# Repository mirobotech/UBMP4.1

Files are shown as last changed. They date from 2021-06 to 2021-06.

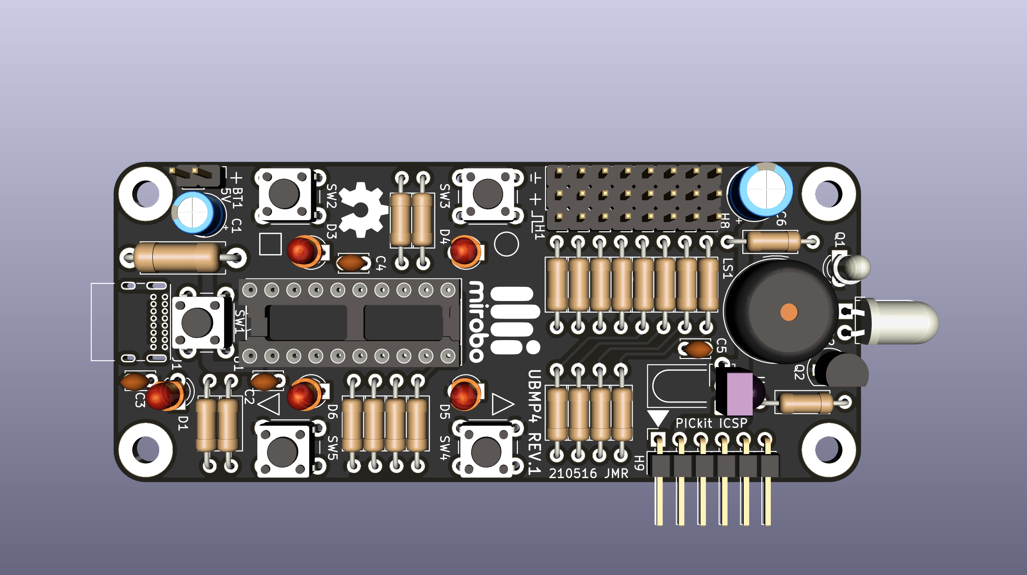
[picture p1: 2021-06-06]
UBMP4.1-top-black.png

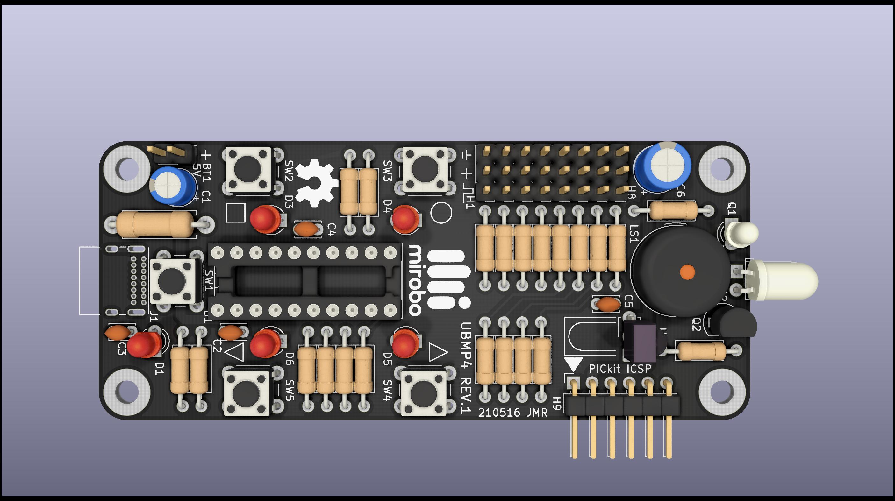
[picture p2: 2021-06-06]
UBMP4.1-top-black.jpg

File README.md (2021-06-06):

# UBMP4.1

UBMP4.1 (USB-Based Beginner Multipurpose Project 4 rev. 1) KiCad schematic and PCB design files.

UBMP4 1-top-black

UBMP4.1 is a development board for learning or teaching PICmicro programming in C using almost any device – including Chromebooks!

## UBMP4.1 Hardware Features

- Microchip PIC16F1459 USB-capable microcontroller with 8k words of program FLASH (6k words free when using the USB bootloader), 128B of user FLASH, 1kB of RAM, 10-bit ADC, and a built-in temperature sensor
- 5 built-in pushbuttons
- 5 visible light LEDs
- 1 piezo beeper output
- optional 8-pin header for PORTC I/O pin expansion (great for servos, a SONAR module, NeoPixels, an LCD, etc.)
- optional IR LED output for remote control transmitter applications (or a high-current transistor-driven output)
- optional IR demodulator for remote control decoding
- optional IR phototransistor or visible-light ambient light sensor for light sensing
- USB 2.0 type-C port for power and programming
- 6-pin ICSP (In-Circuit Serial Programming) header for PICkit-4

## UBMP4.1 Software Features

UBMP4.1 uses the [USB uC](https://github.com/johnnydrazzi/USB-uC) bootloader, which makes UBMP4.1 appear as a USB mass storage device. Programs can be developed in C or assembly code using Microchip Technology's MPLAB X IDE or the MPLAB Xpress web-based IDE, or in any programming language or software that creates a Microchip-compatible .hex output file.

Just plug UBMP4.1 into a USB port, wait for it to appear on your computer as drive ***PIC16F1459***, and drag your compiled .hex file onto the drive. UMBP4.1 starts running your program as soon as the .hex file is transferred.

## UMBP4.1 is Open

UBMP4.1 is open hardware and uses open source software. The following permissions and conditions apply to UBMP4.1:
- the KiCad UBMP4.1 files stored in GitHub are open hardware licensed under the terms of the MIT license (except the mirobo.tech logo - see below)
- UBMP4.1 programs stored in GitHub are open source software licensed under the terms of the MIT license
- UMBP4.1 learning materials on the mirobo.tech website are licensed under the terms of the Creative Commons CC-BY 4.0 license
- the USB uC bootloader is open source and licensed under the terms of the GPL3.0 license by John Izzard
- the mirobo.tech logo mark is a trademark of mirobo Technolgy and may not be used without prior permission

## Where can I buy UBMP4.1?

UBMP4.1 boards and kits are available at [mirobo.tech](https://mirobo.tech/ubmp4).  
Bare UBMP4.1 printed circuit boards are also available from [OSHPARK](https://oshpark.com/shared_projects/b04AabPV).

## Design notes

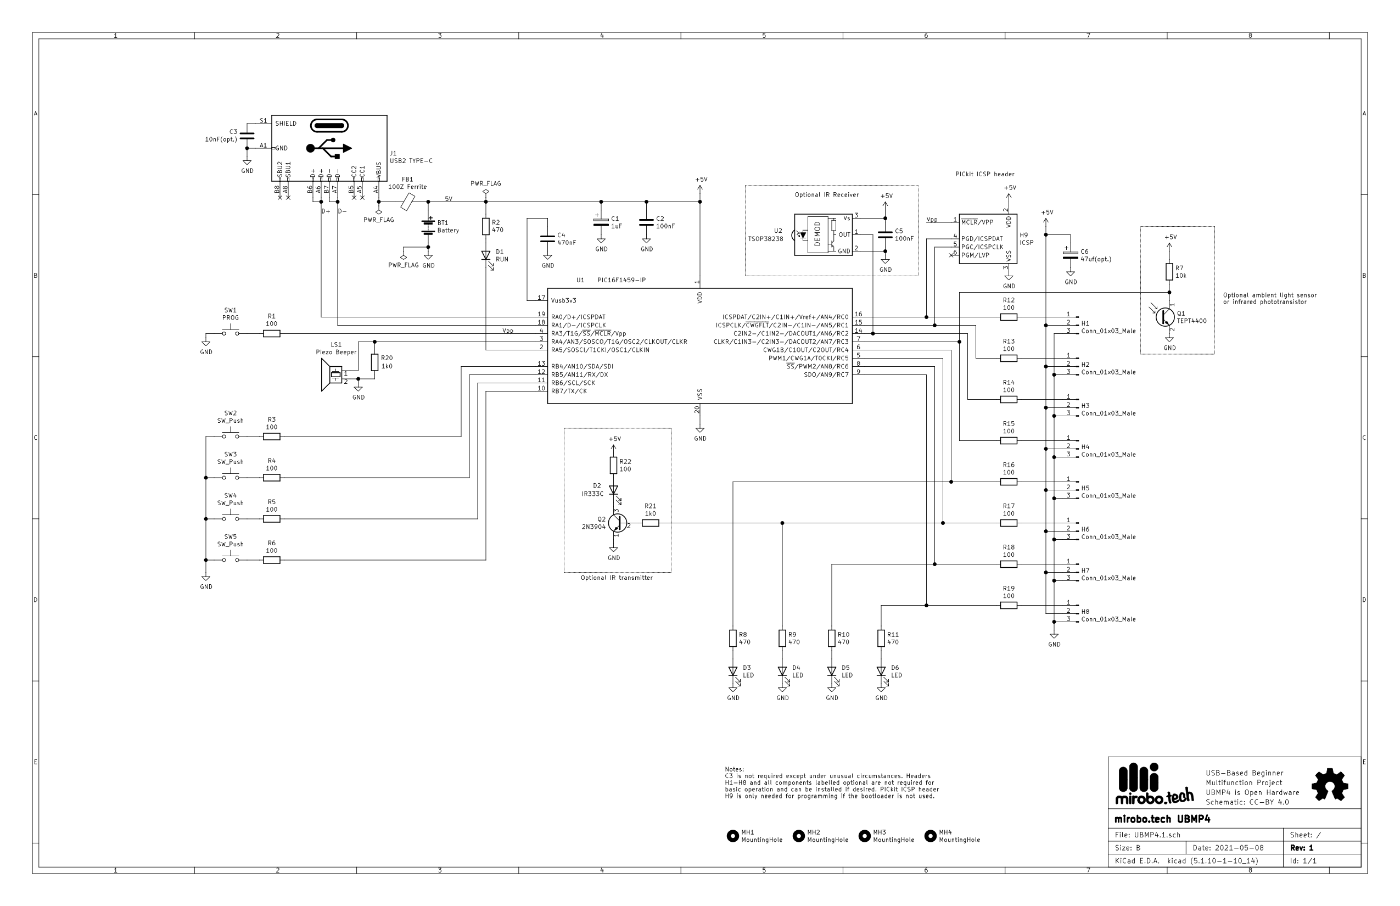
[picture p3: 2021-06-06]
UBMP4.1b.png

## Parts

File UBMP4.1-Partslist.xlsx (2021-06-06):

mirobo.tech UBMP4.1 Parts List
Item | Qty. | Reference(s) | Value | Description | Manuf. Part # | Digi-Key Part # | Datasheet
1 | 1 | UBMP4.1 PCB |  | UBMP4.1 printed circuit board | UBMP41 | ~ | ~
2 | 1 | BT1 | Solder contact (opt.) | Power lead solder pads or 0.1” connector |  | ~ | ~
3 | 1 | C1 | 1uF, 25V | Monolithic capacitor |  | 399-9714-ND | https://content.kemet.com/datasheets/KEM_C1050_GOLDMAX_X7R.pdf
4 | 2 | C2, C5 | 100nF, 100V | Monolithic capacitor |  | 399-9713-ND | https://content.kemet.com/datasheets/KEM_C1050_GOLDMAX_X7R.pdf
5 | 1 | C3 | 10nF, 50V (opt.) | Monolithic capacitor |  | 399-4148-ND | https://content.kemet.com/datasheets/KEM_C1050_GOLDMAX_X7R.pdf
6 | 1 | C4 | 470nF, 50V | Monolithic capacitor |  | 399-9741-ND | https://content.kemet.com/datasheets/KEM_C1050_GOLDMAX_X7R.pdf
7 | 1 | C6 | 47uf, 16V (opt.) | Electrolytic capacitor |  |  | ~
8 | 1 | D1 | 3mm LED | Program/Run LED | LTL-4232N | 160-1143-ND | ~
9 | 1 | D2 | IR LED (opt.) | Lumex IR LED for IR remote control transmission | OED-EL-1L2 | 67-1001-ND | https://www.lumex.com/datasheet/OED-EL-1L2
10 | 4 | D3, D4, D5, D6 | 3mm LED | User I/O LEDs | LTL-4251N | 160-1145-ND | ~
12 | 1 | FB1 | 100Z ferrite bead | Laird ferrite bead 100Ω @ 25 MHz | 28L0138-40R-10 | 28L0138-40R-10 240-2439-1-ND | https://media.digikey.com/pdf/Data%20Sheets/Laird%20Technologies/EMI_Filtering_and_RF_Inductors.pdf
13 | 8 | H1, H2, H3, H4, H5, H6, H7, H8 | 01x03 0.1” pin header (opt.) | I/O header posts for servos, external modules | PBC36SAAN | S1011E-36-ND | ~
15 | 1 | H9 | 01x06 0.1” RA pin header (opt.) | PICkit ICSP programming header | PBC36SBAN | S1111E-36-ND | http://ww1.microchip.com/downloads/en/devicedoc/30277d.pdf
16 | 1 | J1 | USB2 TYPE-C | GCT USB2 Type-C power/prog. connector | USB4085-GF-A | 2073-USB4085-GF-ACT-ND | https://media.digikey.com/pdf/Data%20Sheets/GCT%20PDFs/Ionex_USB_Conn_Br.pdf
17 | 1 | LS1 | Piezo beeper | TDK 12.2mm piezo audio transducer | PS1240P02BT | 445-2525-1-ND | ~
18A | 1 | Q1 | Ambient light sensor (opt.) | Vishay ambient light sensor | TEPT4400 | 751-1057-ND | https://www.vishay.com/docs/81341/tept4400.pdf
18B | 1 | Q1 | IR phototransistor (opt.) | Lite-On IR phototransistor | LTR-4206E | 160-1030-ND | https://optoelectronics.liteon.com/upload/download/DS-50-92-0073/R4206E.pdf
19 | 1 | Q2 | 2N3904 | NPN transistor | 2N3904 (generic) | 2N3904FS-ND | https://www.onsemi.com/pdf/datasheet/pzt3904-d.pdf
20 | 14 | R1, R3, R4, R5, R6, R12, R13, R14, R15, R16, R17, R18, R19, R22 | 100Ω, 1/4W | 5% carbon film resistor | 100Ω (generic) | 100QBK-ND | ~
21 | 5 | R2, R8, R9, R10, R11 | 470Ω, 1/4W | 5% carbon film resistor | 470Ω (generic) | 470QBK-ND | ~
22 | 1 | R7 | 10kΩ, 1/4W | 5% carbon film resistor | 10kΩ (generic) | 10KQBK-ND | ~
24 | 2 | R20, R21 | 1k0Ω, 1/4W | 5% carbon film resistor | 1.0kΩ (generic) | 1.0KQBK-ND | ~
25 | 5 | SW1, SW2, SW3, SW4, SW5 | 6mm pushbutton | Omron 6mm momentary pushbutton | B3F-1000 | SW400-ND | ~
26 | 1 | U1 | PIC16F1459-I/P | Microchip Technology PIC16F1459 USB-capable microcontroller | PIC16F1459-I/P | PIC16F1459-I/P-ND | https://www.microchip.com/wwwproducts/en/PIC16F1459
27 | 1 | U2 | TSOP38238 (opt.) | Vishay 38kHz IR demodulator | TSOP38238 | 751-1227-ND | http://www.vishay.com/docs/82491/tsop382.pdf
 | 58 | Total Components

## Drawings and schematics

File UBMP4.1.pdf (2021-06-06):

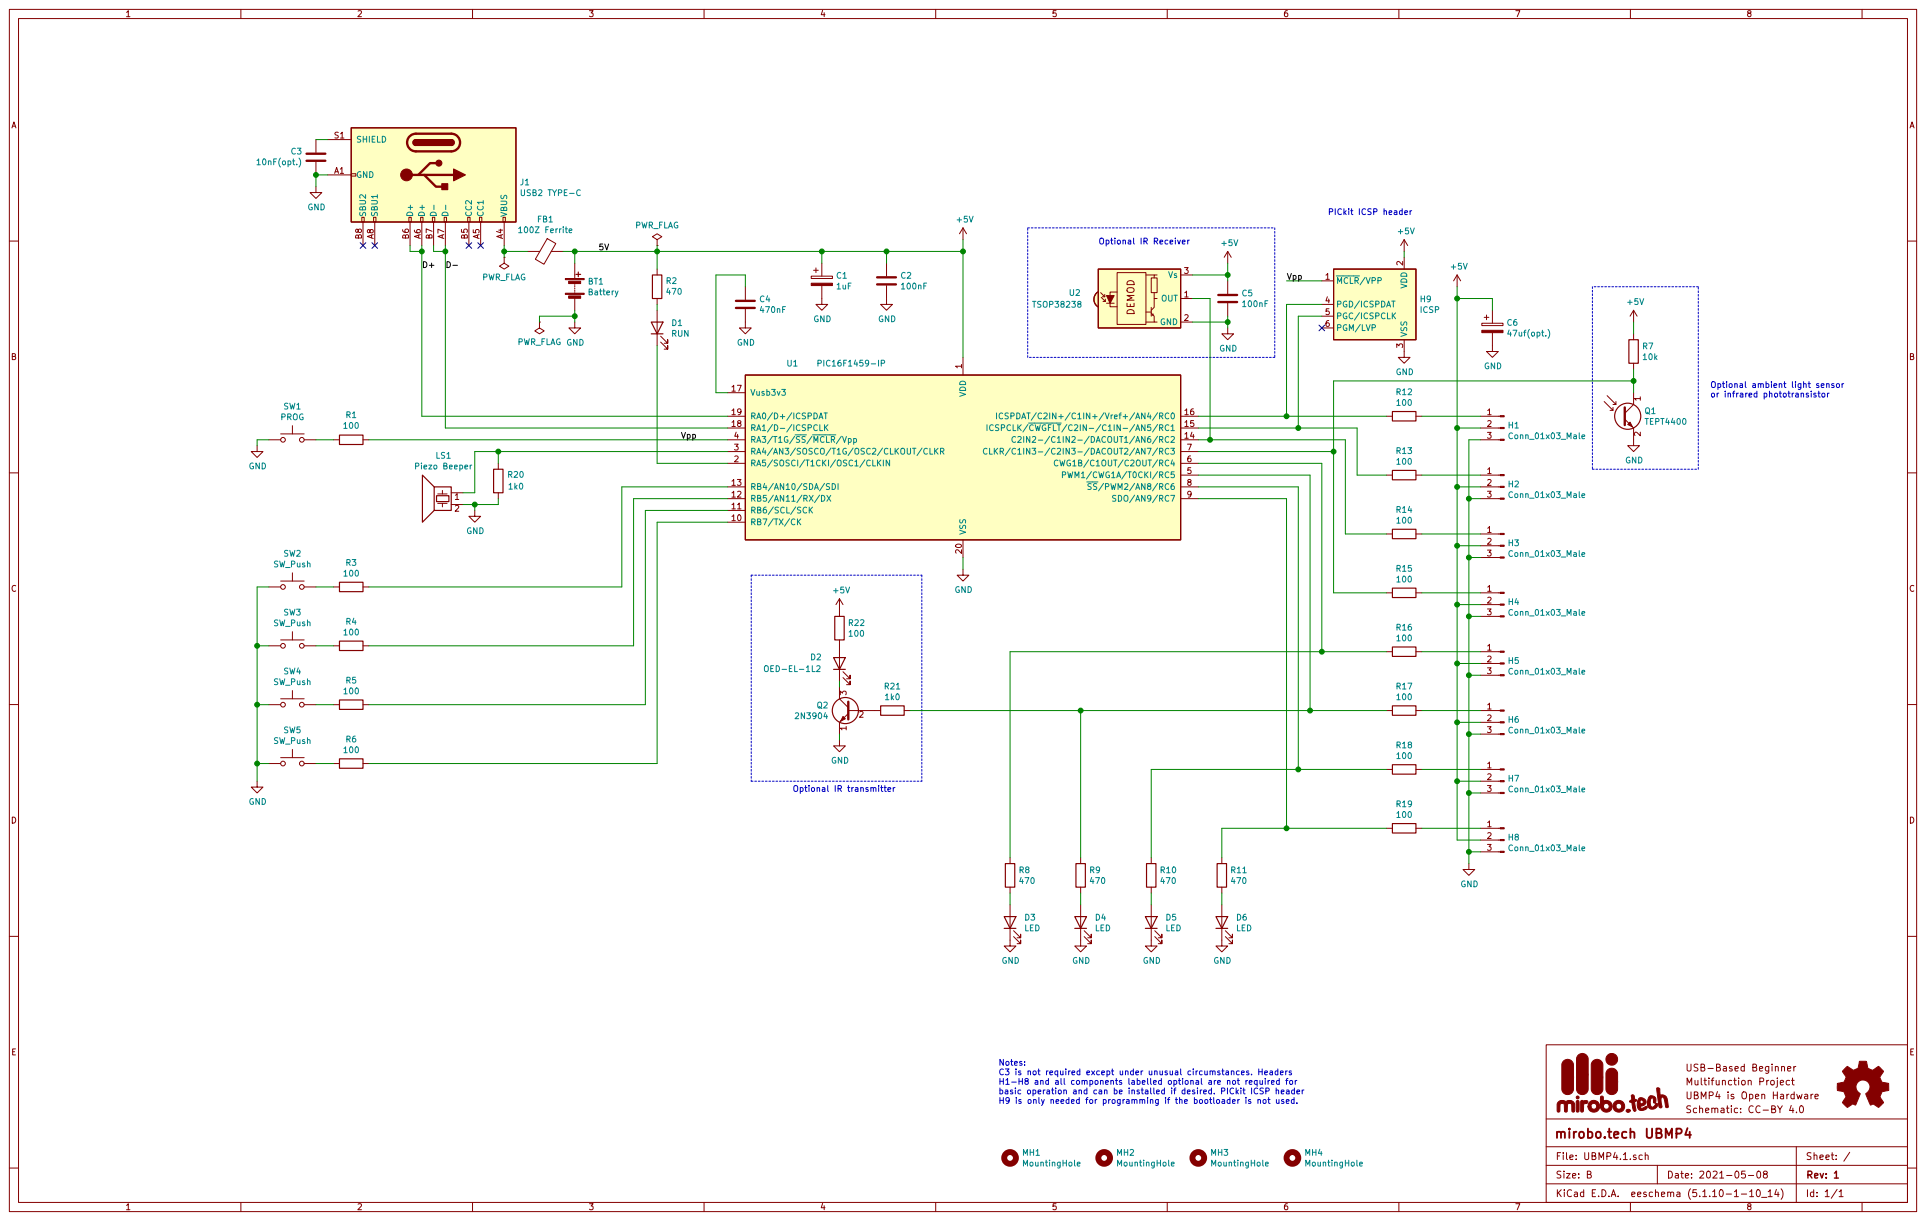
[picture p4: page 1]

3 PGD/ICSPDAT 4 PGC/ICSPCLK 5 PGM/LVP 6 H9 DEMOD ICSP OUT 1 GND 2 Vs 3 U2 TSOP38238 C4

1 RB7/TX/CK 10 RB6/SCL/SCK 11 RB5/AN11/RX/DX 12 RB4/AN10/SDA/SDI 13 C2IN2-/C1IN2-/DACOUT1/AN6/RC2 14

100 MH4 MountingHole MH3 MountingHole MH2 MountingHole MH1 MountingHole

Notes: C3 is not required except under unusual circumstances. Headers

USB-Based Beginner
Multifunction Project
Schematic: CC-BY 4.0 UBMP4 is Open Hardware

H1-H8 and all components labelled optional are not required for
basic operation and can be installed if desired. PICkit ICSP header
H9 is only needed for programming if the bootloader is not used.

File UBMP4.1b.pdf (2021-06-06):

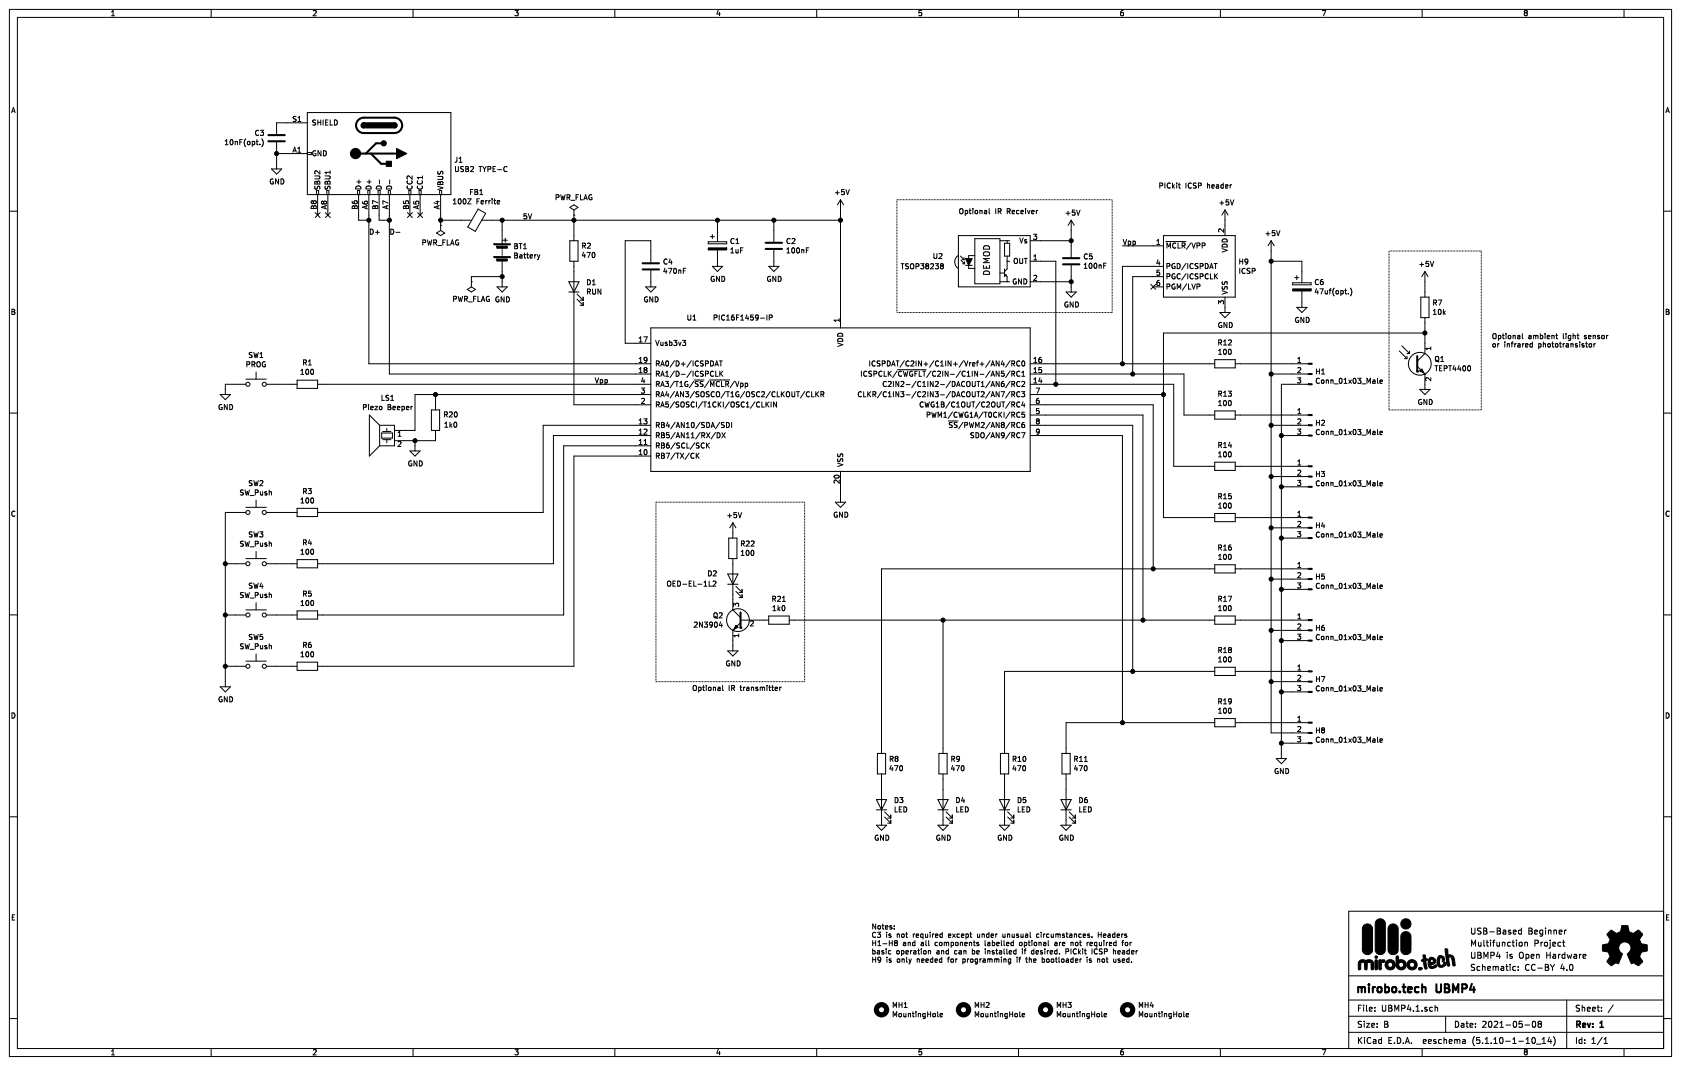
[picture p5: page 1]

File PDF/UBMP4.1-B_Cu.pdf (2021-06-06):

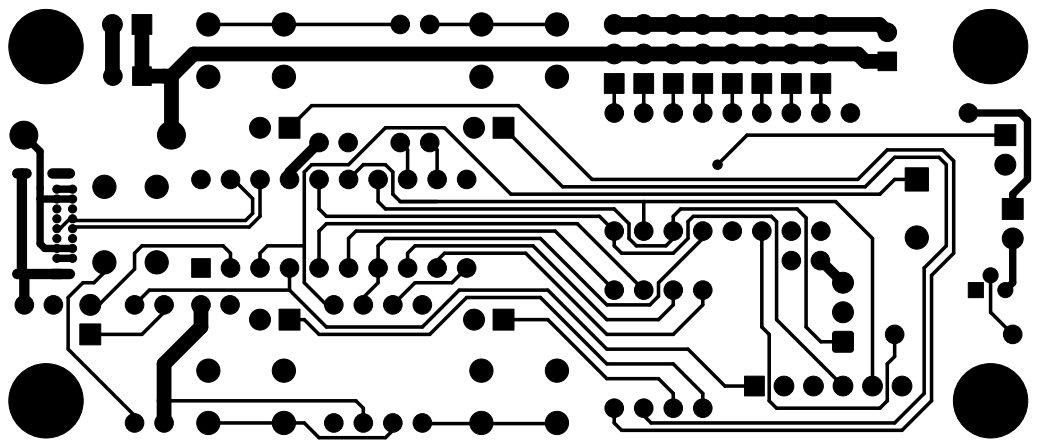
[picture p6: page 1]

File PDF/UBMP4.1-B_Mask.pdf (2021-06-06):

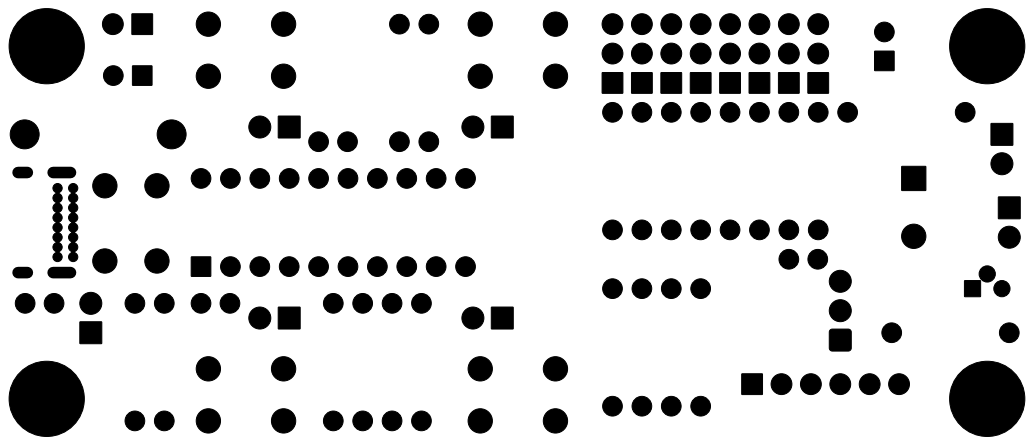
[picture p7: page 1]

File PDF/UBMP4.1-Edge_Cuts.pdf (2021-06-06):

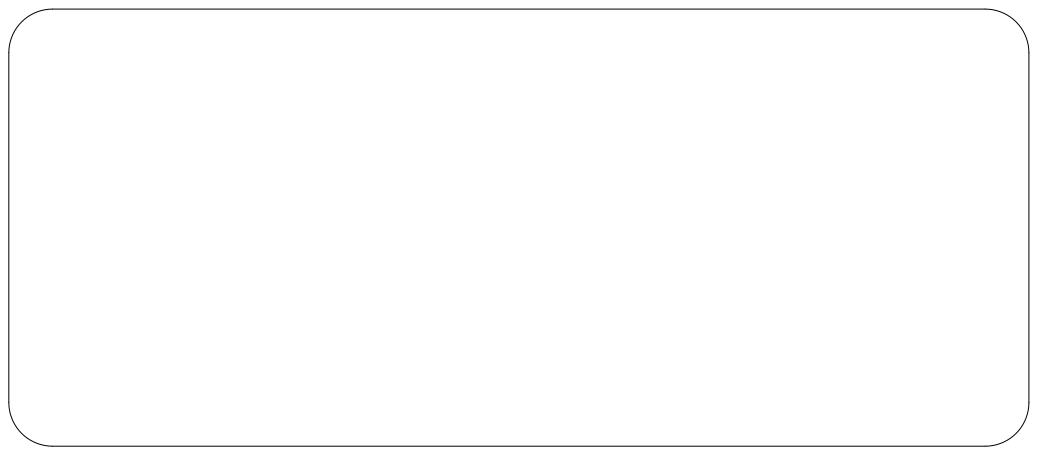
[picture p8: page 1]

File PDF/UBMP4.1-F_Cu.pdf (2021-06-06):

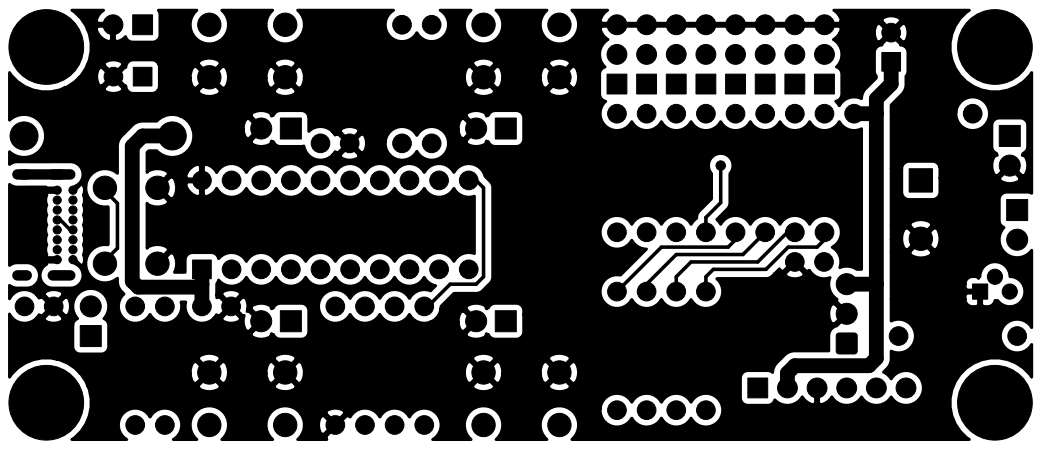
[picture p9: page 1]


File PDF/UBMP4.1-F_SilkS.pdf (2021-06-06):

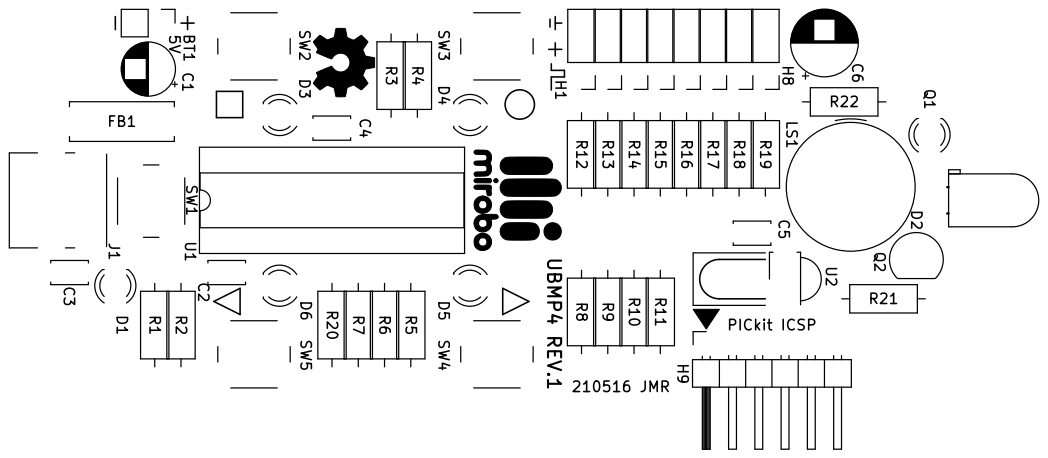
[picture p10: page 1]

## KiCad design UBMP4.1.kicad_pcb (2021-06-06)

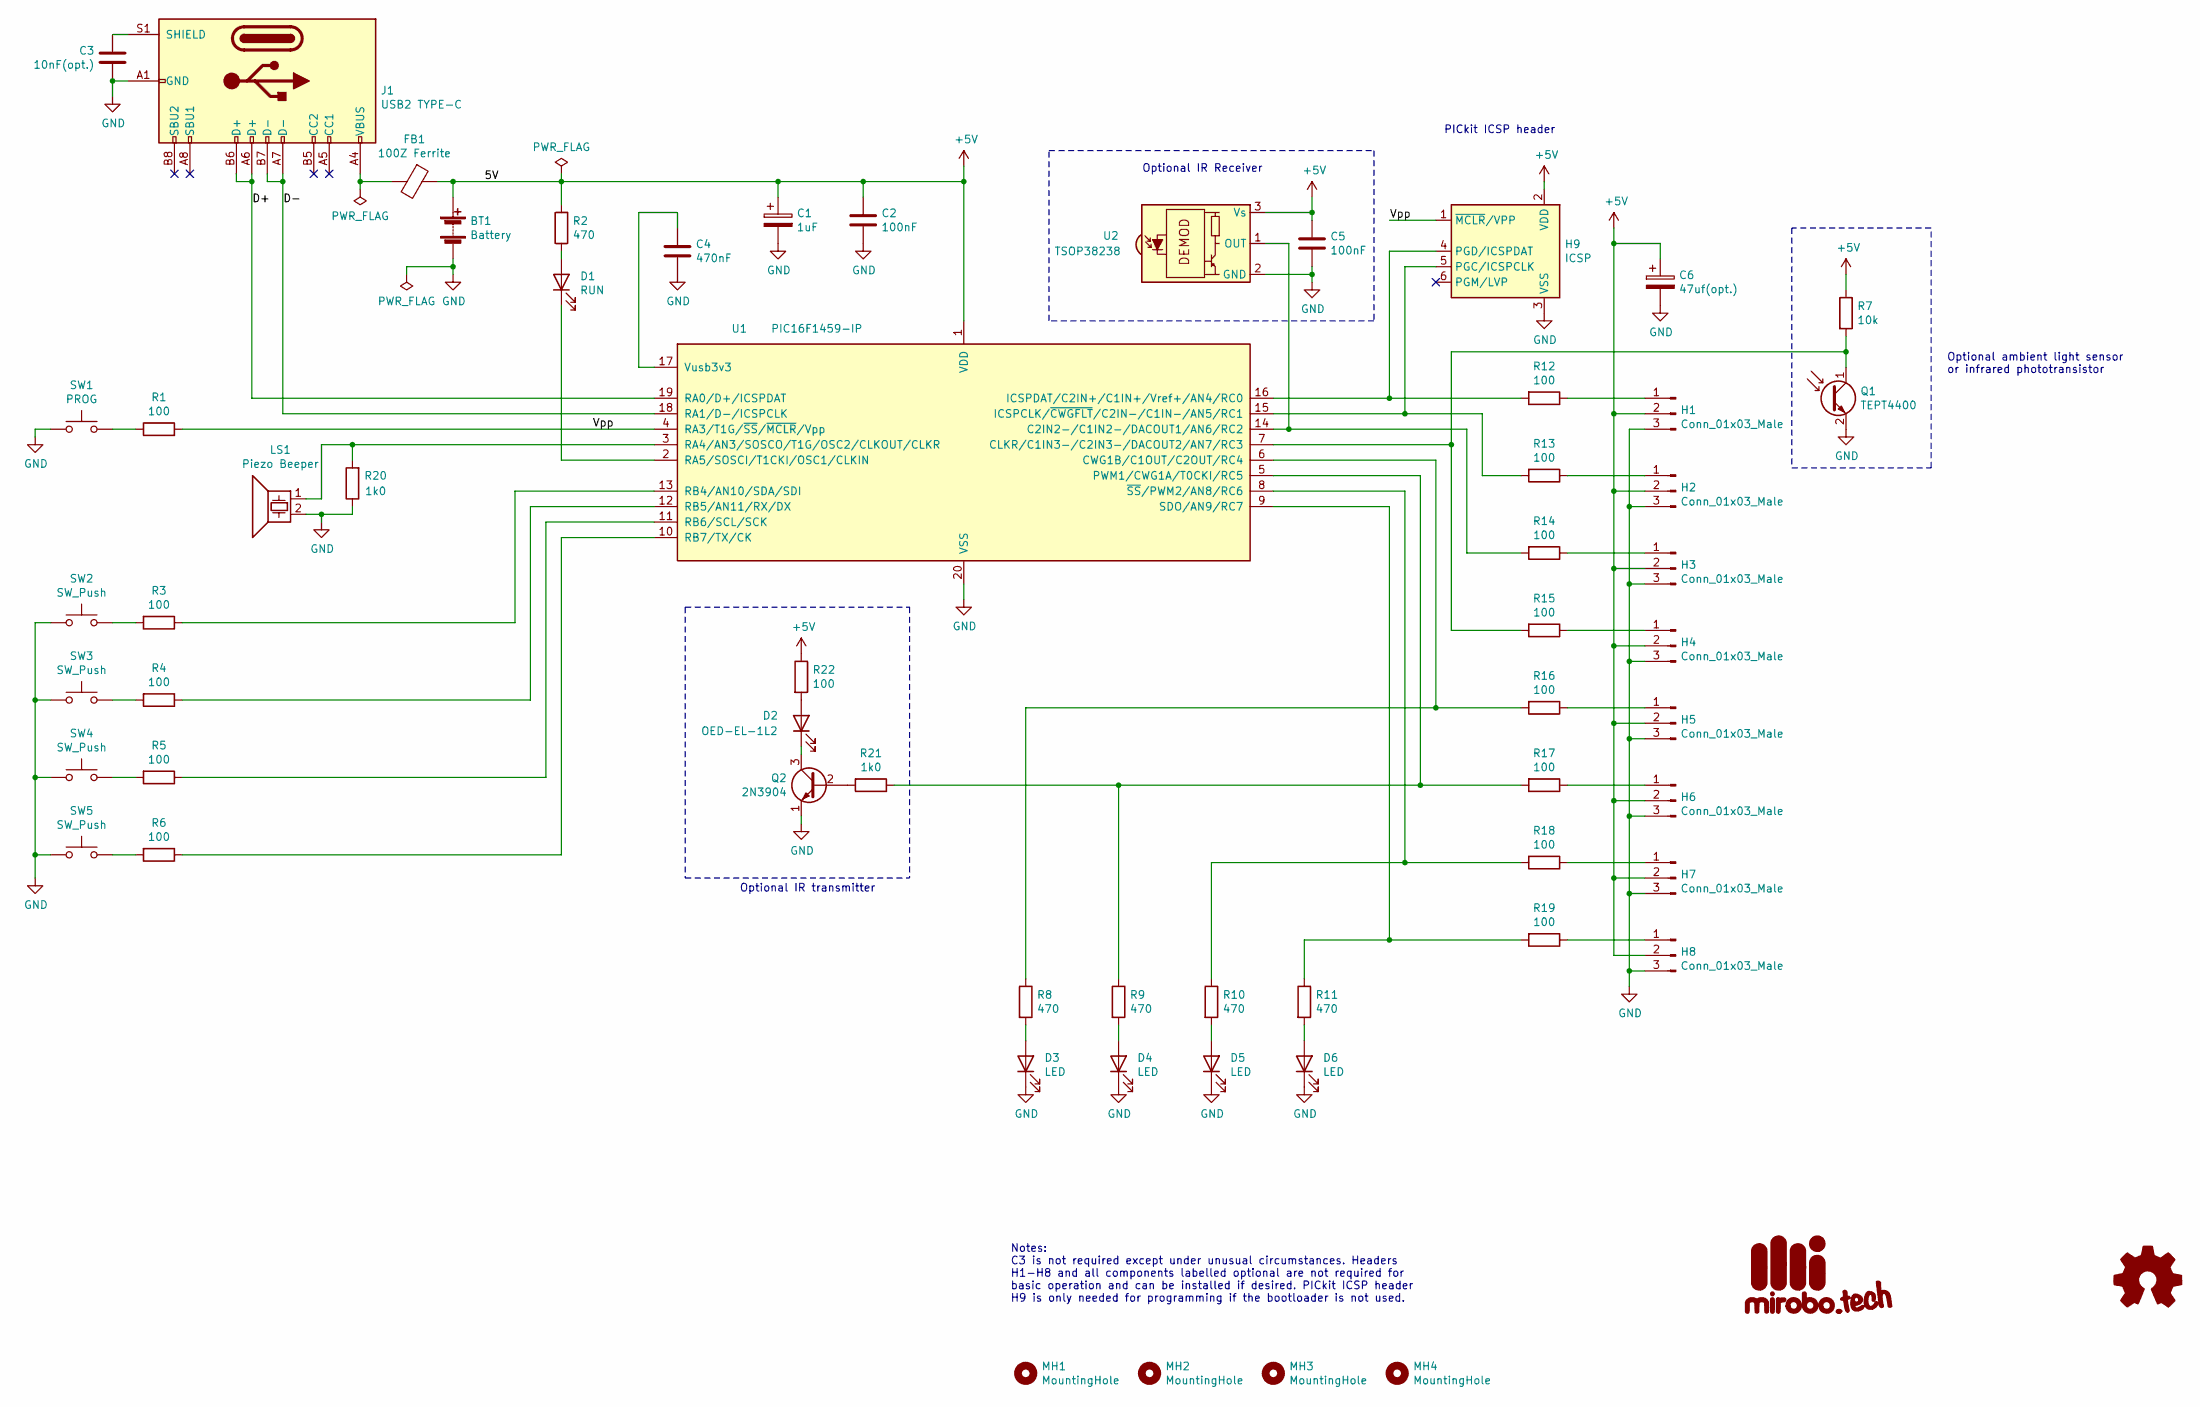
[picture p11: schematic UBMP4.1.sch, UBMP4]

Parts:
BT1: Battery; PinHeader_1x02_P2.54mm_Vertical
C1: 1uF; CP_Radial_D5.0mm_P2.50mm
C2, C5: 100nF; C_Disc_D3.4mm_W2.1mm_P2.50mm
C3: 10nF(opt.); C_Disc_D3.4mm_W2.1mm_P2.50mm
C4: 470nF; C_Disc_D3.4mm_W2.1mm_P2.50mm
C6: 47uf(opt.); CP_Radial_D6.3mm_P2.50mm
D1: RUN; LED_D3.0mm
D2: OED-EL-1L2; LED_D5.0mm_Horizontal_O1.27mm_Z3.0mm_Clear
D3, D4, D5, D6: LED; LED_D3.0mm
FB1: 100Z Ferrite; R_Axial_DIN0411_L9.9mm_D3.6mm_P12.70mm_Horizontal
G1: mirobotech_logo; mirobo_logo_10
G2: Logo_Open_Hardware_Small; OSHW-Symbol_6.7x6mm_SilkScreen
H1, H2, H3, H4, H5, H6, H7, H8: Conn_01x03_Male; PinHeader_1x03_P2.54mm_Vertical
H9: ICSP; PinHeader_1x06_P2.54mm_Horizontal
J1: USB2 TYPE-C; USB_C_Receptacle_GCT_USB4085
LS1: Piezo Beeper; Buzzer_TDK_PS1240P02BT_D12.2mm_H6.5mm
MH1, MH2, MH3, MH4: MountingHole; MountingHole_3.2mm_M3_Pad
Q1: TEPT4400; LED_D3.0mm_Clear
Q2: 2N3904; TO-92
R1, R3, R4, R5, R6, R12, R13, R14, R15, R16, R17, R18, R19, R22: 100; R_Axial_DIN0207_L6.3mm_D2.5mm_P10.16mm_Horizontal
R2, R8, R9, R10, R11: 470; R_Axial_DIN0207_L6.3mm_D2.5mm_P10.16mm_Horizontal
R7: 10k; R_Axial_DIN0207_L6.3mm_D2.5mm_P10.16mm_Horizontal
R20, R21: 1k0; R_Axial_DIN0207_L6.3mm_D2.5mm_P10.16mm_Horizontal
SW1: PROG; SW_PUSH_6mm
SW2, SW3, SW4, SW5: SW_Push; SW_PUSH_6mm
U1: PIC16F1459-IP; DIP-20_W7.62mm_Socket
U2: TSOP38238; Vishay_MINICAST-3Pin

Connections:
+5V: BT1.1 (+), C1.1, C2.1, C5.1, C6.1, FB1.1, H1.2, H2.2, H3.2, H4.2, H5.2, H6.2, H7.2, H8.2, H9.2 (VDD), R2.2, R7.1, R22.1, U1.1 (VDD), U2.3 (Vs)
/D+: J1.A6 (D+), J1.B6 (D+), U1.19 (RA0/D+/ICSPDAT)
/D-: J1.A7 (D-), J1.B7 (D-), U1.18 (RA1/D-/ICSPCLK)
/Vpp: H9.1 (~MCLR~/VPP), R1.2, U1.4 (RA3/T1G/~SS~/~MCLR~/Vpp)
GND: BT1.2 (-), C1.2, C2.2, C3.1, C4.2, C5.2, C6.2, D3.1 (K), D4.1 (K), D5.1 (K), D6.1 (K), H1.3, H2.3, H3.3, H4.3, H5.3, H6.3, H7.3, H8.3, H9.3 (VSS), J1.A1 (GND), J1.A12 (GND), J1.B1 (GND), J1.B12 (GND), LS1.2, Q1.2 (E), Q2.1 (E), R20.1, SW1.1, SW2.1, SW3.1, SW4.1, SW5.1, U1.20 (VSS), U2.2 (GND)
unnamed: C3.2, J1.S1 (SHIELD)
unnamed: C4.1, U1.17 (Vusb3v3)
unnamed: D1.1 (K), U1.2 (RA5/SOSCI/T1CKI/OSC1/CLKIN)
unnamed: D1.2 (A), R2.1
unnamed: D2.1 (K), Q2.3 (C)
unnamed: D2.2 (A), R22.2
unnamed: D3.2 (A), R8.2
unnamed: D4.2 (A), R9.2
unnamed: D5.2 (A), R10.2
unnamed: D6.2 (A), R11.2
unnamed: FB1.2, J1.A4 (VBUS), J1.A9 (VBUS), J1.B4 (VBUS), J1.B9 (VBUS)
unnamed: H1.1, R12.1
unnamed: H2.1, R13.1
unnamed: H3.1, R14.1
unnamed: H4.1, R15.1
unnamed: H5.1, R16.1
unnamed: H6.1, R17.1
unnamed: H7.1, R18.1
unnamed: H8.1, R19.1
unnamed: H9.4 (PGD/ICSPDAT), R12.2, U1.16 (ICSPDAT/C2IN+/C1IN+/Vref+/AN4/RC0)
unnamed: H9.5 (PGC/ICSPCLK), R13.2, U1.15 (ICSPCLK/~CWGFLT~/C2IN-/C1IN-/AN5/RC1)
unnamed: LS1.1, R20.2, U1.3 (RA4/AN3/SOSCO/T1G/OSC2/CLKOUT/CLKR)
unnamed: Q1.1 (C), R7.2, R15.2, U1.7 (CLKR/C1IN3-/C2IN3-/DACOUT2/AN7/RC3)
unnamed: Q2.2 (B), R21.2
unnamed: R1.1, SW1.2
unnamed: R3.1, U1.13 (RB4/AN10/SDA/SDI)
unnamed: R3.2, SW2.2
unnamed: R4.1, U1.12 (RB5/AN11/RX/DX)
unnamed: R4.2, SW3.2
unnamed: R5.1, U1.11 (RB6/SCL/SCK)
unnamed: R5.2, SW4.2
unnamed: R6.1, U1.10 (RB7/TX/CK)
unnamed: R6.2, SW5.2
unnamed: R10.1, R18.2, U1.8 (~SS~/PWM2/AN8/RC6)
unnamed: R11.1, R19.2, U1.9 (SDO/AN9/RC7)
unnamed: R14.2, U1.14 (C2IN2-/C1IN2-/DACOUT1/AN6/RC2), U2.1 (OUT)
unnamed: R8.1, R16.2, U1.6 (CWG1B/C1OUT/C2OUT/RC4)
unnamed: R9.1, R17.2, R21.1, U1.5 (PWM1/CWG1A/T0CKI/RC5)

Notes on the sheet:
Optional IR Receiver
Optional IR transmitter
PICkit ICSP header
Optional ambient light sensor or infrared phototransistor
Notes: C3 is not required except under unusual circumstances. Headers H1-H8 and all components labelled optional are not required for basic operation and can be installed if desired. PICkit ICSP header H9 is only needed for programming if the bootloader is not used.

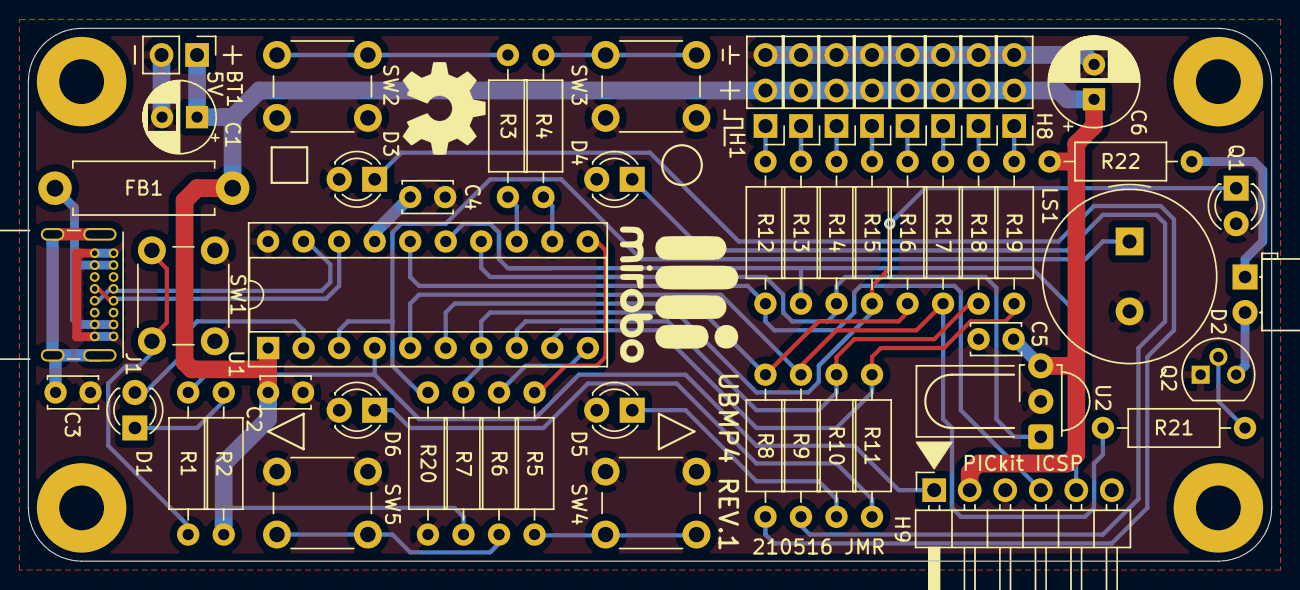
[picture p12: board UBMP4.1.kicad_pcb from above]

Board: 2 copper layers, 88.9 x 38.1 mm, 62 parts (0 on the bottom side), 43 nets.
